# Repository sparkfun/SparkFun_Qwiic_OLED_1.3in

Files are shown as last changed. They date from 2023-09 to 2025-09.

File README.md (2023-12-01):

SparkFun Qwiic OLED 1.3in (128 x 64 white pixels)
========================================

Qwiic OLED 1.3in (128 x 64 white pixels) (https://www.sparkfun.com/products/23453)

[*Qwiic OLED 1.3in (128 x 64 white pixels) (LCD-23453)*](https://www.sparkfun.com/products/23453)

The SparkFun Qwiic OLED 1.3in (128 x 64 white pixels) Breakout is a Qwiic-enabled OLED display.

Repository Contents
-------------------

* **/Hardware** - Eagle design files (.brd, .sch)

Documentation
--------------
* **[Library](https://github.com/sparkfun/SparkFun_Qwiic_OLED_Arduino_Library)** - Latest Arduino library for the SparkFun Qwiic OLED 1.3in Breakout.
* **[Hookup Guide](https://docs.sparkfun.com/SparkFun_Qwiic_OLED_1.3in)** - Basic hookup guide for the SparkFun Qwiic OLED 1.3in

License Information
-------------------

This product is _**open source**_! 

Please review the LICENSE.md file for license information. 

If you have any questions or concerns on licensing, please contact techsupport@sparkfun.com.

Distributed as-is; no warranty is given.

- Your friends at SparkFun.

_<COLLABORATION CREDIT>_

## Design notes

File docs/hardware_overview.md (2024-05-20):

---
icon: material/cog
---

## OLED 

The OLED screen has a pixel resolution of 128 x 64, a panel size of 34.5 x 23.0 x 1.4 (mm), and an active area of 29.42 x 14.7 (mm). The driver chip is the SSD1306. More information can be found in the [datasheet](assets/board_files/SSD1306.pdf).

<figure markdown>
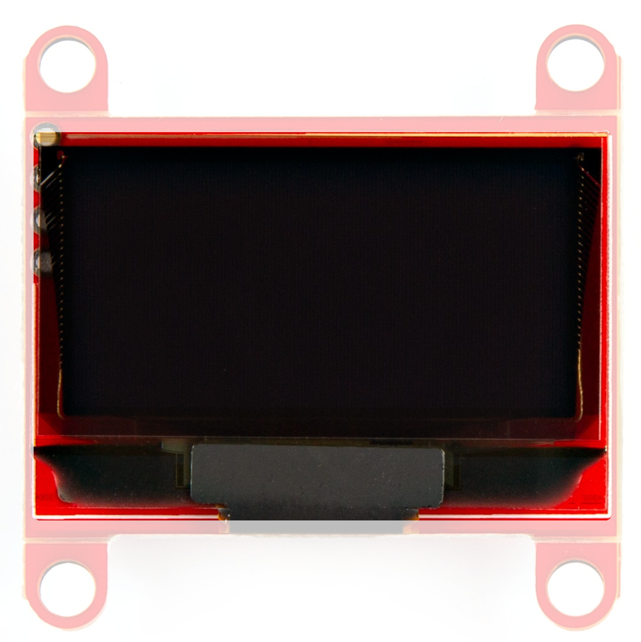
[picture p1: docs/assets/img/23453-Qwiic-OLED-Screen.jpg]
OLED Screen

<figcaption markdown>OLED Screen</figcaption>
</figure>

## Power

Ideally, power is supplied by the Qwiic connector, but the 3V3 and GND pins have been broken out to plated through holes on the side of the board (along with the Clock and Data Lines). Input voltage should not exceed <b>3.3V</b>, as there is no voltage regulation on this breakout. 

<figure markdown>
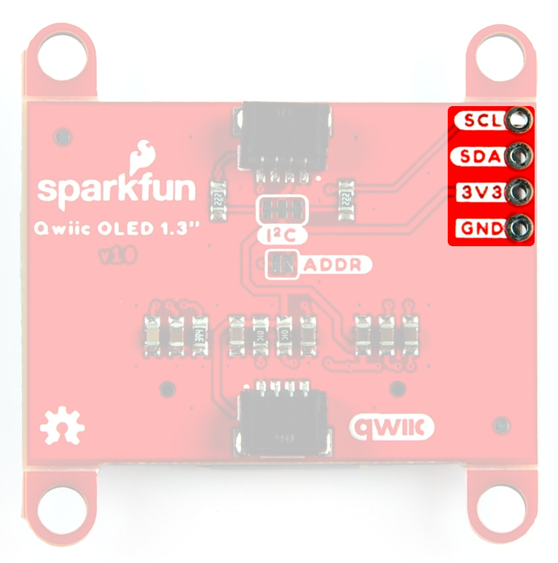
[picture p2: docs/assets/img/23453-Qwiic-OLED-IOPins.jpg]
Power Options

<figcaption markdown>Power Options</figcaption>
</figure>

## Qwiic connectors

The board includes Qwiic connectors that provide power and I<sup>2</sup>C connectivity simultaneously.

For users that need to solder directly to the board, the pins are also broken out on the edge PTH. The I<sup>2</sup>C data and clock lines are also tied to 2.2kΩ pull-up resistors.

<figure markdown>
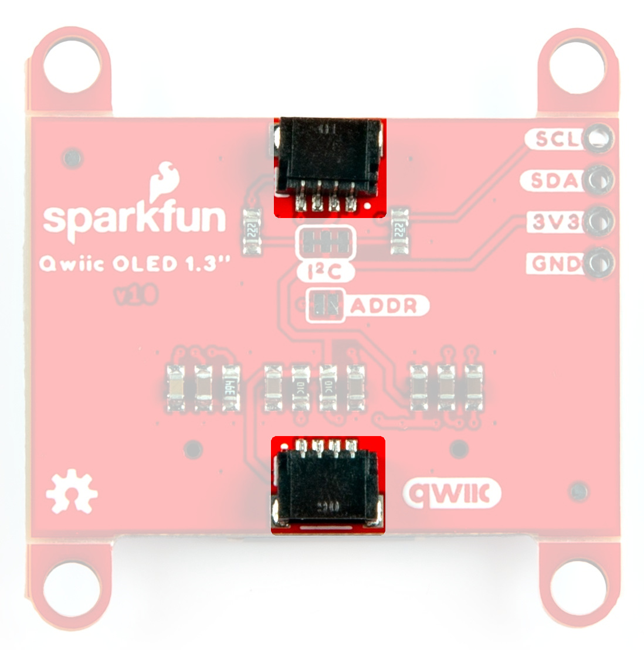
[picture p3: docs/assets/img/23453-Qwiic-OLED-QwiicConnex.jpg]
Qwiic connectors

<figcaption markdown>Qwiic connectors</figcaption>
</figure>

## Jumpers

??? note "Never modified a jumper before?"
	Check out our <a href="https://learn.sparkfun.com/tutorials/664">Jumper Pads and PCB Traces tutorial</a> for a quick introduction!
	<p align="center">
		<a href="https://learn.sparkfun.com/tutorials/664">
		Tutorial's thumbnail<br>
        How to Work with Jumper Pads and PCB Traces</a>
	</p>

### Address Jumper

The SparkFun Qwiic OLED 1.3in board has a default I<sup>2</sup>C address of 0x3D, but by soldering the address jumper on the back of the board, you can select 0x3C. 

<figure markdown>
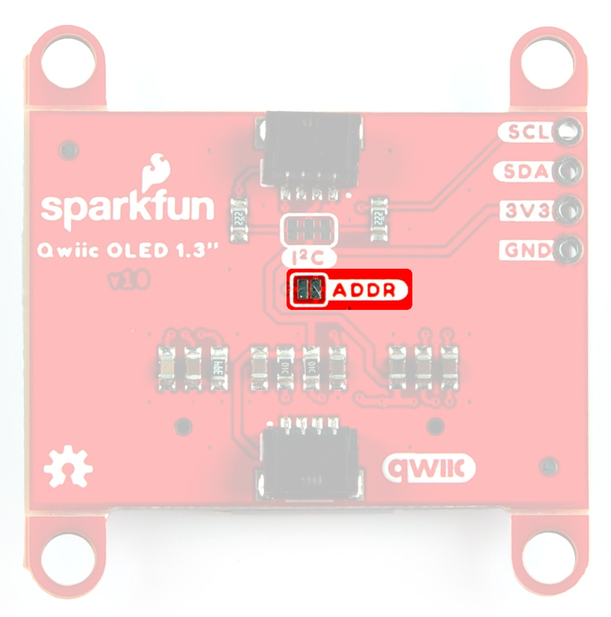
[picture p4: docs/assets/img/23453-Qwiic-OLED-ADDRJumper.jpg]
Address Jumper

<figcaption markdown>Address Jumper</figcaption>
</figure>

### I<sup>2</sup>C Jumper

Like our other Qwiic boards, the SparkFun Qwiic OLED 1.3in comes equipped with pull-up resistors on the clock and data pins. If you are daisy-chaining multiple Qwiic devices, you will want to cut this jumper; if multiple sensors are connected to the bus with the pull-up resistors enabled, the parallel equivalent resistance will create too strong of a pull-up for the bus to operate correctly. As a general rule of thumb, disable all but one pair of pull-up resistors if multiple devices are connected to the bus. To disable the pull up resistors, use an X-acto knife to cut the joint between the jumper pads highlighted below.

<figure markdown>
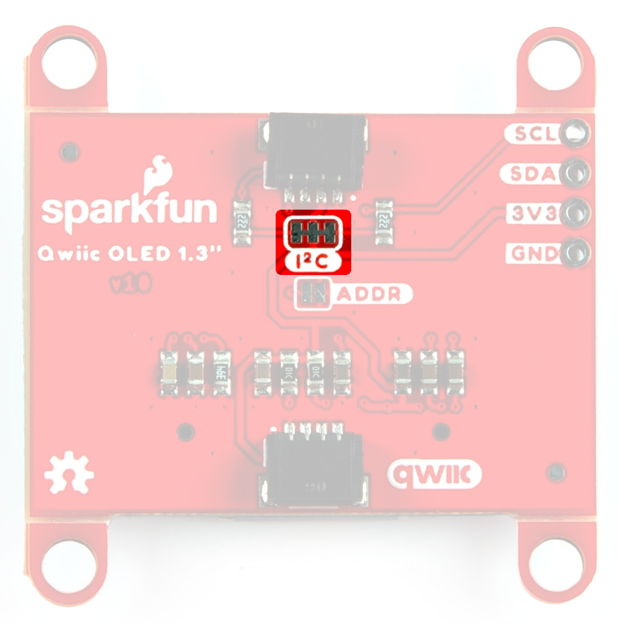
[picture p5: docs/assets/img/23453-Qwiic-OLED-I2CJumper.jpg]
I2C Jumper

<figcaption markdown>I<sup>2</sup>C Jumper</figcaption>
</figure>

## Board Dimensions

The board dimensions are illustrated in the drawing below; the listed measurements are in inches.

<figure markdown>
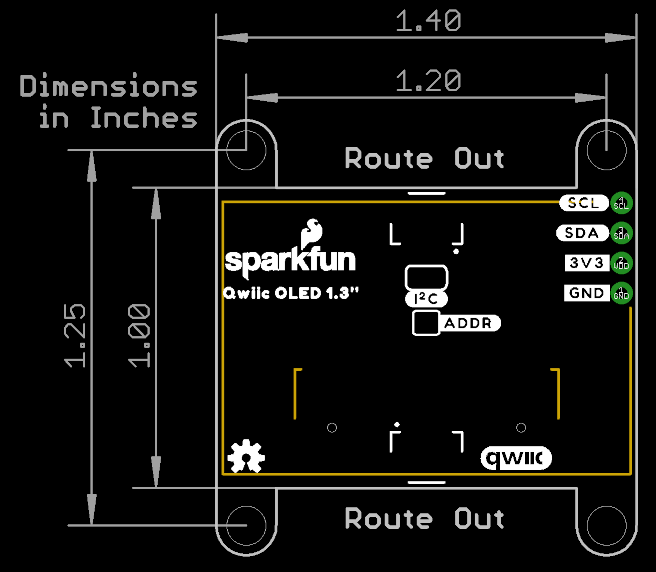
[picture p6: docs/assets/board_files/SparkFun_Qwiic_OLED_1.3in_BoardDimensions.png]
ESP32 Qwiic Pro Mini Board Dimensions

<figcaption markdown>SparkFun Qwiic OLED 1.3in Board Dimensions</figcaption>
</figure>

??? tip "Need more measurements?"
	For more information about the board's dimensions, users can download the [Eagle files](assets/board_files/Qwiic_OLED_1.3in.zip) for the 1" x 1" board, or the [Eagle files](assets/board_files/Qwiic_OLED_1.3in.zip) for the Mini board. These files can be opened in Eagle and additional measurements can be made with the dimensions tool.

	??? info ":octicons-download-16:{ .heart } Eagle - Free Download!"
		Eagle is a [CAD]("computer-aided design") program for electronics that is free to use for hobbyists and students. However, it does require an account registration to utilize the software.

		<center>
		[Download from<br>:autodesk-primary:{ .autodesk }](https://www.autodesk.com/products/eagle/free-download "Go to downloads page"){ .md-button .md-button--primary width="250px" }
		</center>
	
	??? info ":straight_ruler: Dimensions Tool"
		This video from Autodesk demonstrates how to utilize the dimensions tool in Eagle, to include additional measurements:

		<center>
		<div class="video">
		<iframe src="https://www.youtube.com/embed/dZLNd1FtNB8" title="EAGLE Dimension Tool" frameborder="0" allow="accelerometer; autoplay; clipboard-write; encrypted-media; gyroscope; picture-in-picture" allowfullscreen></iframe>
		</div>
		</center>

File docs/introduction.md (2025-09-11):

---
icon: material/book-open-page-variant
---

<div class="grid cards desc" markdown>

- <figure markdown>
    SparkFun Qwiic OLED 1.3in (128 x 64 white pixels) (LCD-23453) (https://www.sparkfun.com/sparkfun-qwiic-oled-1-3in-128x64.html)
		</figure>

    <center>
    [Purchase from SparkFun :fontawesome-solid-cart-plus:{ .heart }](https://www.sparkfun.com/sparkfun-qwiic-oled-1-3in-128x64.html){ .md-button .md-button--primary }
    </center>

</div>

## Required Materials

To follow along with this tutorial, you will need the following materials. You may not need everything though depending on what you have. Add it to your cart, read through the guide, and adjust the cart as necessary.

<div class="grid cards hide col-4" markdown>

-   <a href="https://www.sparkfun.com/products/23453">
      <figure markdown>
        SparkFun Qwiic OLED 1.3in (128 x 64 white pixels)
      </figure>
    </a>

    ---

    <a href="https://www.sparkfun.com/products/23453">
      <b>SparkFun Qwiic OLED 1.3in (128 x 64 white pixels)</b>
      <br />
      LCD-23453
    </a>

-   <a href="https://www.sparkfun.com/products/15123">
      <figure markdown>
        SparkFun RedBoard Qwiic
      </figure>
    </a>

    ---

    <a href="https://www.sparkfun.com/products/15123">
      <b>SparkFun RedBoard Qwiic</b>
      <br />
      DEV-15123
    </a>

-   <a href="https://www.sparkfun.com/products/14427">
      <figure markdown>
        Qwiic Cable - 100mm
      </figure>
    </a>

    ---

    <a href="https://www.sparkfun.com/products/14427">
      <b>Qwiic Cable - 100mm</b>
      <br>
      PRT-14427
    </a>
</div>

## Suggested Reading

This board is part of the [Qwiic connect system](https://www.sparkfun.com/qwiic). We recommend familiarizing yourself with the **Logic Levels** and **I<sup>2</sup>C** tutorials.  Click on the banner to learn more about [Qwiic products](https://www.sparkfun.com/qwiic).
<center>
<div align="center">
    <div style="top:5px;left:5px;background-color:Gray;position:relative">
        <div style="top:-5px;left:-5px;background-color:#ffffff;position:relative;border:1px solid black;">
            <a href="https://www.sparkfun.com/qwiic">Qwiic Connect System</a>
        </div>
    </div>
</div>
</center>

<center>
    <iframe width="600" height="327" src="https://www.youtube.com/embed/x0RDEHqFIF8" title="SparkFun's Qwiic Connect System" frameborder="0" allow="accelerometer; autoplay; clipboard-write; encrypted-media; gyroscope; picture-in-picture" allowfullscreen></iframe>
</center>

Below are a few tutorials that may help users familiarize themselves with various aspects of the board.

<div class="grid cards hide col-4" markdown>

-   <a href="https://learn.sparkfun.com/tutorials/how-to-solder-through-hole-soldering">
      <figure markdown>
        How to Solder: Through Hole Soldering
      </figure>
    </a>

    ---

    <a href="https://learn.sparkfun.com/tutorials/how-to-solder-through-hole-soldering">
      <b>How to Solder: Through Hole Soldering</b>
    </a>

-   <a href="https://learn.sparkfun.com/tutorials/analog-vs-digital">
      <figure markdown>
        Analog vs. Digital
      </figure>
    </a>

    ---

    <a href="https://learn.sparkfun.com/tutorials/analog-vs-digital">
      <b>Analog vs. Digital</b>
    </a>

-   <a href="https://learn.sparkfun.com/tutorials/serial-peripheral-interface-spi">
      <figure markdown>
        Serial Peripheral Interface
      </figure>
    </a>

    ---

    <a href="https://learn.sparkfun.com/tutorials/serial-peripheral-interface-spi">
      <b>Serial Peripheral Interface</b>
    </a>

-   <a href="https://learn.sparkfun.com/tutorials/i2c">
      <figure markdown>
        I2C
      </figure>
    </a>

    ---

    <a href="https://learn.sparkfun.com/tutorials/i2c">
      <b>I2C</b>
    </a>
</div>

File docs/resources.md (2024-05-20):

<!-- This section should include all the relevant documentation and product files (Eagle files, schematic, datasheet(s), landing pages, etc. and any relevant tutorials to go beyond the Hookup Guide.) -->

For more resources related to the SparkFun Qwiic OLED 1.3in, check out the links listed here: 

* [Schematic (PDF)](assets/board_files/SparkFun_Qwiic_OLED_1.3in_Schematic.pdf){ target="_blank" }
* [Eagle Files (ZIP)](assets/board_files/SparkFun_Qwiic_OLED_1.3in.zip){ target="_blank" }
* [Board Dimensions](assets/board_files/SparkFun_Qwiic_OLED_1.3in_BoardDimensions.png){ target="_blank" }
* [SH1306-OLED_Datasheet](assets/board_files/SSD1306.pdf){ target="_blank" }
* [Hardware GitHub Respository](https://github.com/sparkfun/SparkFun_Qwiic_OLED_1.3in){ target="_blank" }
* [Arduino Library GitHub Repo](https://github.com/sparkfun/SparkFun_Qwiic_OLED_Arduino_Library){ target="_blank" }

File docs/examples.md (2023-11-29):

---
icon: simple/arduino
---

The Arduino Library for the SparkFun OLED boards comes with a slew of examples to get you going.  Here we'll just run through a basic "the gang's all here" display. 

!!! note
    This example is pretty specific to the 1.3" OLED board. It requires the entirety of the pixels and would need to be heavily modified to be used by any of our other OLED boards. 

###Example: Display all the things

??? "Example Arduino Code"
	```    
        #include <Wire.h>

        #include <SparkFun_Qwiic_OLED.h> //http://librarymanager/All#SparkFun_Qwiic_OLED
        Qwiic1in3OLED myOLED; // 128x64

        // Fonts
        #include <res/qw_fnt_5x7.h>
        #include <res/qw_fnt_8x16.h>
        #include <res/qw_fnt_31x48.h>
        #include <res/qw_fnt_7segment.h>
        #include <res/qw_fnt_largenum.h>

        void setup()
        {
        Wire.begin();

        myOLED.begin();

        myOLED.erase();
        
        myOLED.setFont(QW_FONT_5X7);
        myOLED.text(0,0,"01234567");

        myOLED.setFont(QW_FONT_5X7);
        myOLED.text(0,8,"ABCDabcd");

        myOLED.setFont(QW_FONT_8X16);
        myOLED.text(48,0,"ABcd");

        myOLED.setFont(QW_FONT_8X16);
        myOLED.text(48,13,"efGH");

        myOLED.setFont(QW_FONT_7SEGMENT);
        myOLED.text(80,0,"0123");

        myOLED.setFont(QW_FONT_5X7);
        myOLED.text(80,17,"ijkLMNO");

        myOLED.setFont(QW_FONT_LARGENUM);
        myOLED.text(0,16,"012");

        myOLED.setFont(QW_FONT_31X48);
        myOLED.text(36,27,"ABC");

        myOLED.display();
        }

        void loop()
        {
        }

	```

Make sure you've selected the correct board and port in the Tools menu and then hit the upload button. You should see something similar to the following. 

<figure markdown>
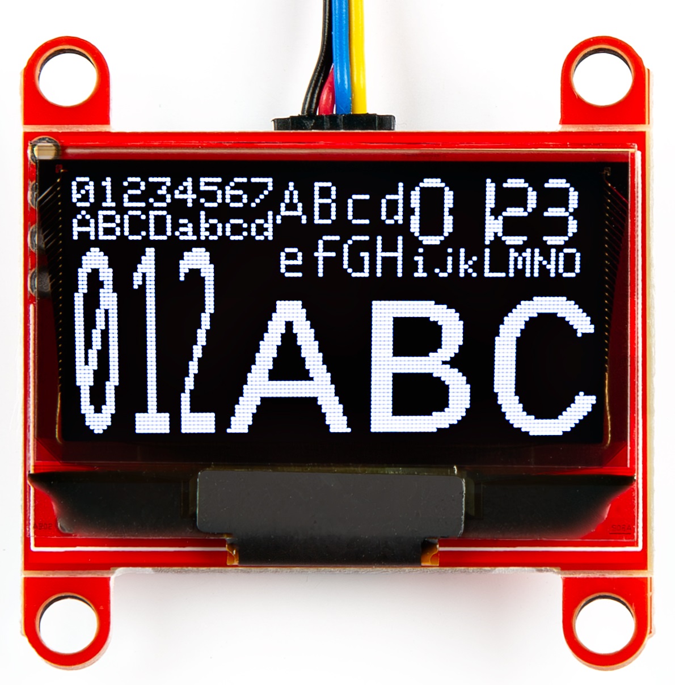
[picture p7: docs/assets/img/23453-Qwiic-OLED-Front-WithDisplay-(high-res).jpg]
Example DisplayScreen

<figcaption markdown>OLED Screen</figcaption>
</figure>

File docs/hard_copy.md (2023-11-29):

---
icon: material/book-open-variant
---

Need to download or print our hookup guide?

* [Print :fontawesome-solid-print:](../single_page) (Single-Page View)
    * To save as a `*.pdf` file, select the **Printer** or **Destination** labeled ++"Save as PDF"++. *(Instructions will vary based on the browser)*

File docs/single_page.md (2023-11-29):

---
hide:
  - navigation
  - toc
icon: fontawesome/solid/scroll
---

--8<-- "./docs/introduction.md:5"

# Hardware Overview
--8<-- "./docs/hardware_overview.md:5"

# Hardware Assembly
--8<-- "./docs/hardware_assembly.md:5"

# Software Setup and Programming
--8<-- "./docs/software_setup_and_programming.md:5"

# Arduino Example
--8<-- "./docs/examples.md:5"

# Resources:
--8<-- "./docs/resources.md"

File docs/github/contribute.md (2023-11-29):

# Contribute: Make an Augmentation!
Spot an improvement opportunity? Feel free to contribute to our open-source design and documentation. 

## :material-file-document-multiple:&nbsp;Improve our Documentation
All of this documentation can be modified by you! Please help us make it better.

* These pages are contained in the [`docs` folder](https://github.com/sparkfun/SparkFun_Qwiic_OLED_1.3in/tree/main/docs) of the [Qwiic OLED 1.3in](https://github.com/sparkfun/SparkFun_Qwiic_OLED_1.3in).

<!-- ### :material-source-pull:&nbsp;Submit a Correction -->
### Submit a Correction

1. With a GitHub account, [fork this repository](https://github.com/sparkfun/SparkFun_Qwiic_OLED_1.3in/fork).
2. Add your corrections or improvements to the markdown file.
3. File a pull request with your changes, and enjoy making the ~~words~~ ~~worlds~~ world a better place.
	* Once received, the documentation specialist will automatically be notified.
	* We will review your suggested improvements to make sure they are correct and fit within our documentation standards.

## :material-cog:&nbsp;Improve our Hardware Design
All of our designs are open-source! Please help us make it better.

* Our board design files are contained in the [`Hardware` folder](https://github.com/sparkfun/SparkFun_Qwiic_OLED_1.3in/tree/main/Hardware) of the [Qwiic OLED 1.3in](https://github.com/sparkfun/SparkFun_Qwiic_OLED_1.3in).

<!-- ### :material-source-pull:&nbsp;Submit a Design Enhancement -->
### Submit a Design Enhancement

1. With a GitHub account, [fork this repository](https://github.com/sparkfun/SparkFun_Qwiic_OLED_1.3in/fork).
2. Add your design augmentation(s)
3. File a pull request with your changes, and enjoy making the ~~words~~ ~~worlds~~ world a better place.
	1. Once received, the engineer in charge of the original design will automatically be notified.
	2. We will review your suggested improvement(s) to verify that they are within our board design standards and meet our product design requirements.
	3. If approved, we will flag these changes for our next board revision. Congrats! 🍻

		!!! info
			Even if your suggestion is accepted, these changes may not be immediately available for purchase. We may have to cycle through our current product inventory first.

## Contributors&nbsp;:clap:
Let's provide some recognition to the contributors for this project!

GitHub Contributors Image
<br>


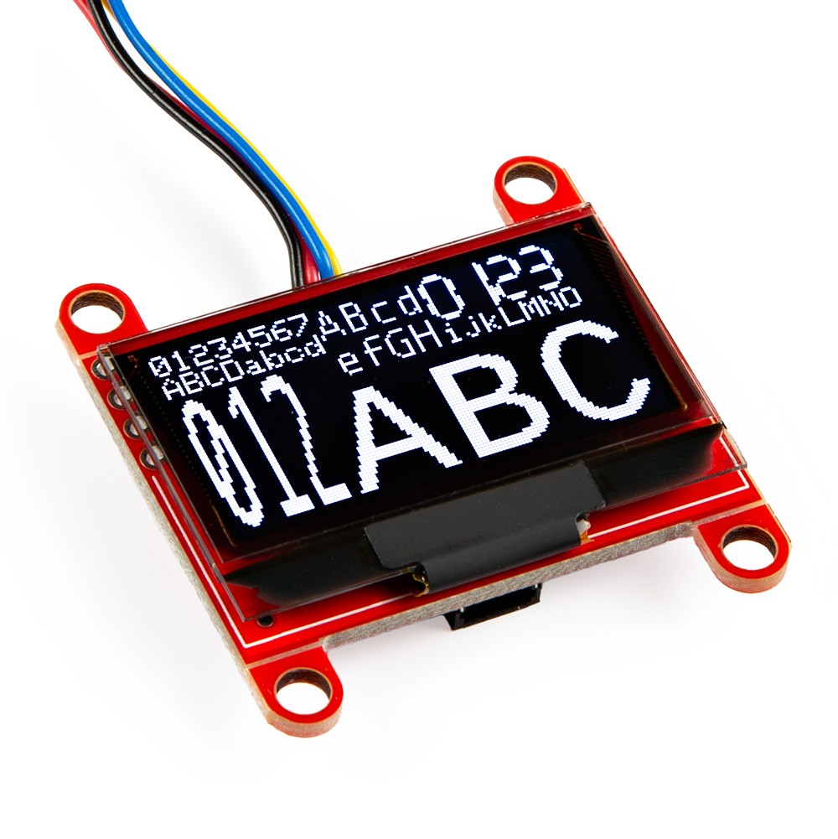
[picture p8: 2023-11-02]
docs/assets/img/23453-Qwiic-OLED-Feature-WithDisplay.jpg

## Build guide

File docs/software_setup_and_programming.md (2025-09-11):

---
icon: simple/arduino
---

!!! arduino

    ### Arduino IDE

    This example assumes you are using the latest version of the Arduino IDE on your desktop. If this is your first time using Arduino IDE and an library, please review the following tutorials.

    - [Installing the Arduino IDE](https://learn.sparkfun.com/tutorials/installing-arduino-ide)
    - [Installing an Arduino Library](https://learn.sparkfun.com/tutorials/installing-an-arduino-library)

SparkFun has leveraged our existing OLED library to work with the SparkFun Qwiic OLED 1.3 board. If you haven't already worked with our OLED boards, you can obtain this library through the Arduino Library Manager by searching for "Qwiic OLED" and installing the latest version. If you prefer downloading libraries manually, you can grab them from the GitHub Repository.

<div style="text-align: center"><a href="https://github.com/sparkfun/SparkFun_Qwiic_OLED_Arduino_Library/archive/refs/heads/main.zip" target="qwiic_oled_arduino_library" class="md-button">SparkFun Qwiic OLED Arduino Library GitHub</a></div>

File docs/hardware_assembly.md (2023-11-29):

---
icon: fontawesome/solid/screwdriver-wrench
---

SparkFun's Qwiic system makes components plug and play. Simply plug one end of your Qwiic cable into the Qwiic connector on your OLED screen and the other end of the Qwiic cable into the controller board (here we're using the RedBoard Qwiic). Now connect your controller board to the computer and voila. You're ready to rock. 

<figure markdown>
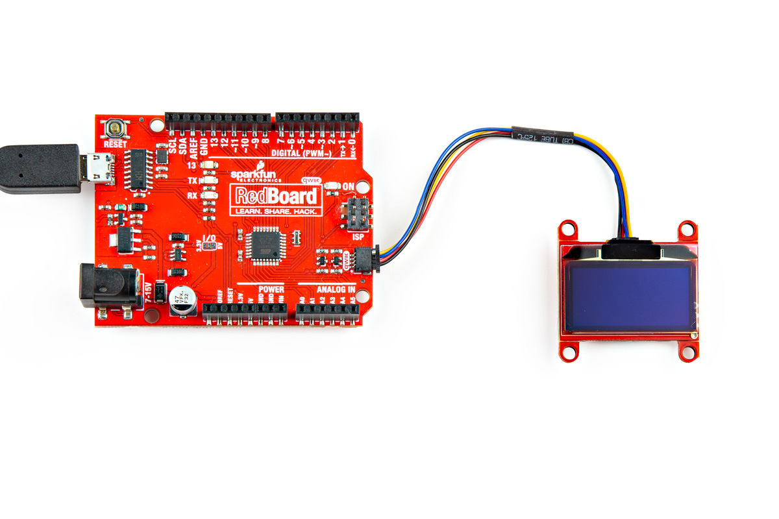
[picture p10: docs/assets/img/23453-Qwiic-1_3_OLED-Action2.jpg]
Qwiic OLED connected to the Qwiic RedBoard

<figcaption markdown>SparkFun Qwiic OLED connected to the SparkFun Qwiic RedBoard</figcaption>
</figure>

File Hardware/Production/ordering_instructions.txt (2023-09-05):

panel size, 122x136mm
PCB thickness, 1.6mm
number of layers, 2
soldermask color, Red
silkscreen color, White
oz copper, 1oz
finish, HASL lead free
stencils, top+bottom
pcs per panel, 9
min trace width, 0.2540mm / 0.0100in
min drill size, 0.3000mm / 0.0118in

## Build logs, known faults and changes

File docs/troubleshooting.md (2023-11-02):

!!! note
    <span class="glyphicon glyphicon-question-sign" aria-hidden="true"></span>
        <strong> Not working as expected and need help? </strong> <br /><br />

    If you need technical assistance and more information on a product that is not working as you expected, we recommend heading on over to the <a href="https://www.sparkfun.com/technical_assistance">SparkFun Technical Assistance</a> page for some initial troubleshooting. <br /><br />

    <div style="text-align: center"><a href="https://www.sparkfun.com/technical_assistance" target="sfe_technical_assistance" class="md-button">SparkFun Technical Assistance Page</a></div>

    If you don't find what you need there, the <a href="https://forum.sparkfun.com/index.php">SparkFun Forums</a> are a great place to find and ask for help. If this is your first visit, you'll need to <a href="https://forum.sparkfun.com/ucp.php?mode=register">create a Forum Account</a> to search product forums and post questions.<br /><br />

    <div style="text-align: center"><a href="https://forum.sparkfun.com/ucp.php?mode=register" class="md-button">Create New Forum Account</a>&nbsp;&nbsp;&nbsp;<a href="https://forum.sparkfun.com/index.php" class="md-button md-button--primary">Log Into SparkFun Forums</a></div>

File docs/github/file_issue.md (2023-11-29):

# Did we make a mistake?

Spot something wrong? Please let us know. 

<!-- Technical Assistance Box -->
!!! warning "Need Help?"
    If you need technical assistance or more information on a product that is not working as you expected, we recommend heading on over to the [SparkFun Technical Assistance](https://www.sparkfun.com/technical_assistanc) page for some initial troubleshooting. This **Submit Issues** page is not where users should seek assistance.

    <center>
    [SparkFun Technical Assistance Page](https://www.sparkfun.com/technical_assistance){ .md-button .md-button--primary }
    </center>
    
    If you can't find what you need there, the [SparkFun Forums](https://forum.sparkfun.com/index.php) is a great place to search the product forums and ask questions.
    
    !!! info "Account Registration Required"
        For your first visit to our forum, you'll need to create a [Forum Account](https://forum.sparkfun.com/ucp.php?mode=register) to post questions.

## Discrepancies in the Documentation

All of our documentation can be modified by you! Please help us make it better.

* The documentation files for these pages are contained in the [`docs` folder](https://github.com/sparkfun/SparkFun_Qwiic_OLED_1.3in/tree/main/docs) of the [Qwiic OLED 1.3in](https://github.com/sparkfun/SparkFun_Qwiic_OLED_1.3in).

### 🔍 Spot something wrong?

If a section of the documentation is incorrect, please [open an issue](https://github.com/sparkfun/SparkFun_Qwiic_OLED_1.3in/issues) and let us know.

### Do you have a suggested correction?

1. With a GitHub account, [fork this repository](https://github.com/sparkfun/SparkFun_Qwiic_OLED_1.3in/fork).
2. Add your correction(s) or improvement(s) to the markdown file(s)
3. File a pull request with your changes, and enjoy making the ~~words~~ ~~worlds~~ world a better place.
	* Once received, the documentation specialist will automatically be notified.
	* We will review your suggested improvement(s) to make sure they are correct and fit within our documentation standards.

## Problems in the Hardware Design

All of our designs are open-source! Please help us make it better.

* Our board design files are contained in the [`Hardware` folder](https://github.com/sparkfun/SparkFun_Qwiic_OLED_1.3in/tree/main/Hardware) of the [Qwiic OLED 1.3in](https://github.com/sparkfun/SparkFun_Qwiic_OLED_1.3in).

### Does something not make sense? 🤔

If part of the design is confusing, please [open an issue](https://github.com/sparkfun/SparkFun_Qwiic_OLED_1.3in/issues) and let us know.

### Did we forget to include an important function of the board? 🤦

If part of the board's functionality is missing, please [open an issue](https://github.com/sparkfun/SparkFun_Qwiic_OLED_1.3in/issues) and file a feature request.

!!! tip "Design Considerations"
	Please keep in mind that we may intentionally exclude certain functions of the board to meet our product design requirements.
	
	* *For example, our Qwiic Micro boards are intended to fit on a small board layout and only use I<sup>2</sup>C communication; therefore, we may not have the SPI and interrupt pins available for users.*

### Do you wish to contribute directly to improving the board design?

1. With a GitHub account, [fork this repository](https://github.com/sparkfun/SparkFun_Qwiic_OLED_1.3in/fork).
2. Add your design augmentation(s)
3. File a pull request with your changes, and enjoy making the ~~words~~ ~~worlds~~ world a better place.
	1. Once received, the engineer in charge of the original design will automatically be notified.
	2. We will review your suggested improvement(s) to verify that they are within our board design standards and meet our product design requirements.
	3. If approved, we will flag these changes for our next board revision. Congrats! 🍻

		!!! info
			Even if your suggestion is accepted, these changes may not be immediately available for purchase. We may have to cycle through our current product inventory first.

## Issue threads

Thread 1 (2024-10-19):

Does it work on a Raspberry Pico?

davidedelvento, 2024-10-19:
Would this display (or another one) work with a Pico? Obviously not with the Arduino library but with something else?

How about the original Teensy v4.1 from PJRC? Would that work out of the box?

Thanks

PaulZC, 2024-10-19:
Hi Davide (@davidedelvento ),

Earle Philhower's RP2040 Arduino board package supports I2C. If you use that, you should find that our [Qwiic OLED Library](https://github.com/sparkfun/SparkFun_Qwiic_OLED_Arduino_Library) works just fine.

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

Best wishes,
Paul

davidedelvento, 2024-10-19:
Sounds great! Thanks a lot Paul, especially for responding during the weekend.
Just for reference for others coming here (and not willing to Google :rofl: ), Earle's Arduino port is a at https://github.com/earlephilhower/arduino-pico

Closed 2024-10-19.

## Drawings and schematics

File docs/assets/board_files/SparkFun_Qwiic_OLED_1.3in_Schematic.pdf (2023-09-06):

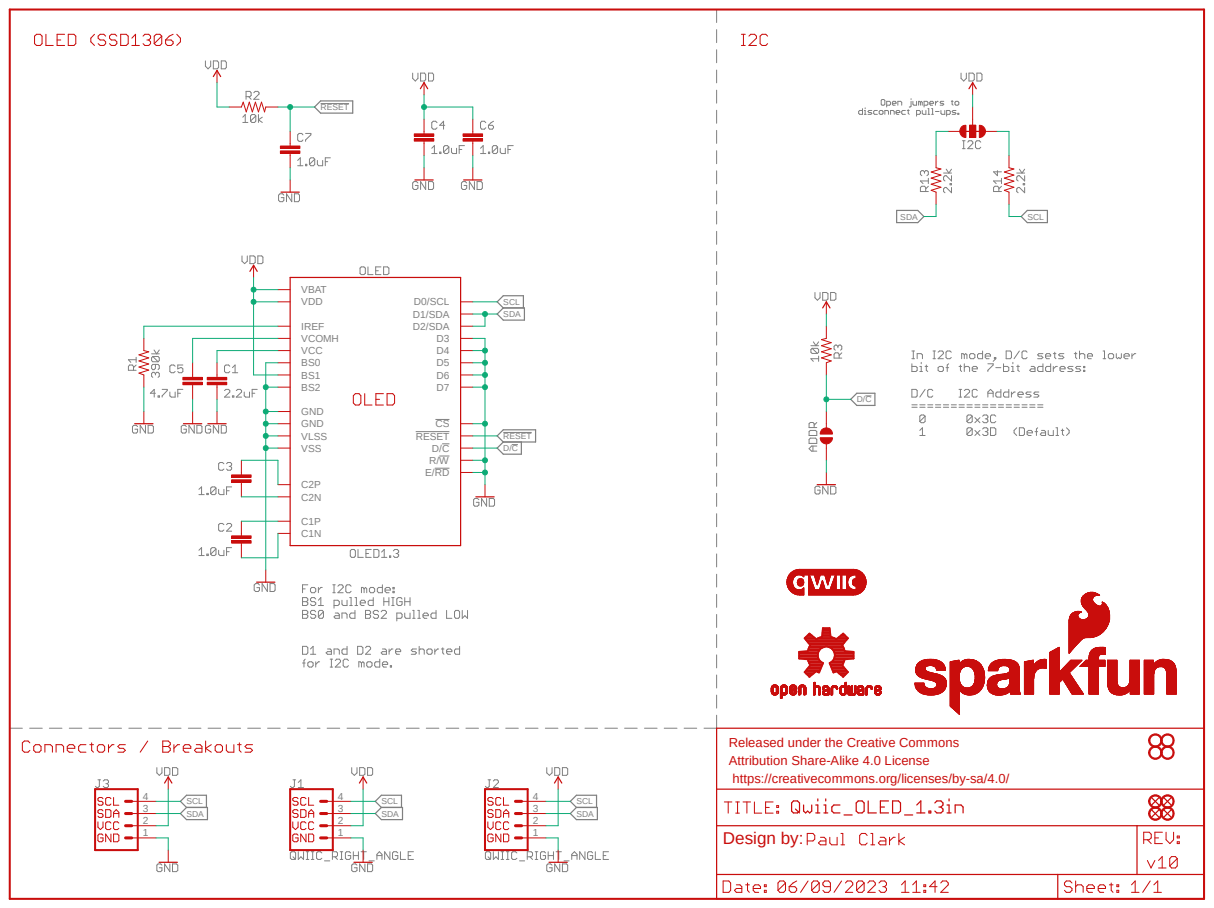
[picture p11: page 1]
CS RESET BS1 BS2 C1N; IREF; VCOMH; VDD; VLSS VSS; SDA; SCL; SCL RESET; RESET; Design by:

VBAT VCC
D0/SCL D1/SDA D2/SDAD3 D4 D5 D6 D7 E/RD GND GND

Released under the Creative Commons
Attribution Share-Alike 4.0 License
https://creativecommons.org/licenses/by-sa/4.0/

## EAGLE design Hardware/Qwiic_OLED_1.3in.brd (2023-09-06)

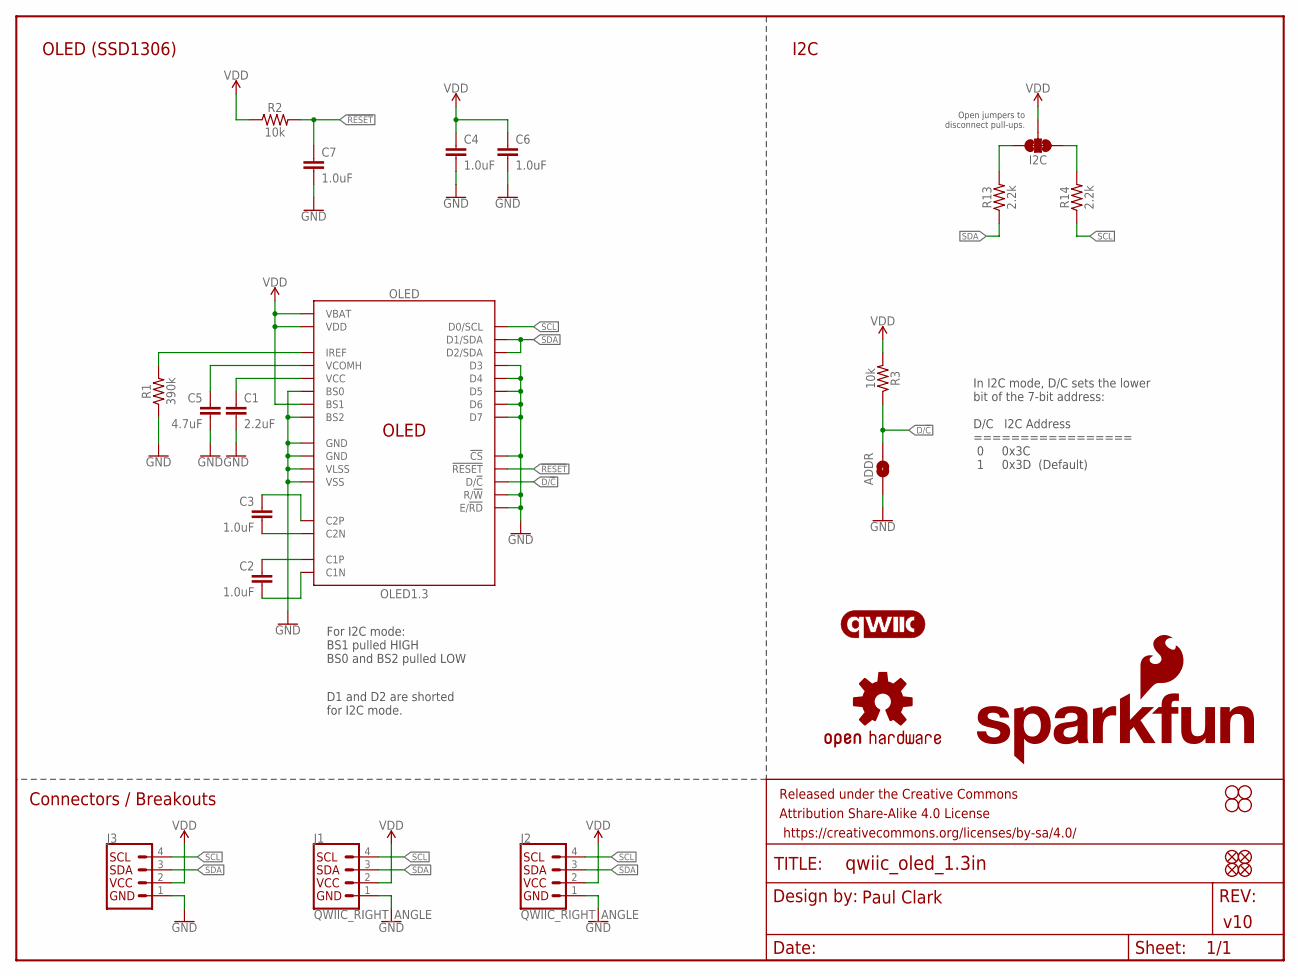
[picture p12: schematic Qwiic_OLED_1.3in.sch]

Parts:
ADDR: JUMPER-SMT_2_NO_SILK; SMT-JUMPER_2_NO_SILK
C1: 2.2uF; 0603
C2, C3, C4, C6, C7: 1.0uF; 0603
C5: 4.7uF; 0603
FID1, FID2, FID3, FID4: FIDUCIAL1X2; FIDUCIAL-1X2
FRAME1: FRAME-LETTER; CREATIVE_COMMONS
H1, H2, H3, H4: STAND-OFF
I2C: JUMPER-SMT_3_2-NC_TRACE_SILK; SMT-JUMPER_3_2-NC_TRACE_SILK
J1, J2: QWIIC_RIGHT_ANGLE; JST04_1MM_RA
J3: I2C_STANDARD_NO_SILK; 1X04_NO_SILK
LOGO1: QWIIC_LOGO_6MM; QWIIC_6MM
LOGO3: OSHW-LOGOS; OSHW-LOGO-S
LOGO4: SFE_LOGO_NAME_FLAME.1_INCH; SFE_LOGO_NAME_FLAME_.1
OLED: OLED1.3; OLED-1.3-128X64
R1: 390k; 0603
R2, R3: 10k; 0603
R13, R14: 2.2k; 0603

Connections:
!RESET!: C7.1, OLED.14 (!RESET!), R2.2
C1N: C2.2, OLED.5 (C1N)
C1P: C2.1, OLED.4 (C1P)
C2N: C3.2, OLED.3 (C2N)
C2P: C3.1, OLED.2 (C2P)
D/!C!: ADDR.2, OLED.15 (D/!C!), R3.1
GND: ADDR.1, C1.2, C4.2, C5.2, C6.2, C7.2, J1.1, J2.1, J3.1 (GND), OLED.1 (GND), OLED.8 (VSS), OLED.10 (BS0), OLED.12 (BS2), OLED.13 (!CS!), OLED.16 (R/!W!), OLED.17 (E/!RD!), OLED.21 (D3), OLED.22 (D4), OLED.23 (D5), OLED.24 (D6), OLED.25 (D7), OLED.29 (VLSS), OLED.30 (GND), R1.1
IREF: OLED.26 (IREF), R1.2
unnamed: I2C.3, R13.2
unnamed: I2C.1, R14.2
SCL: J1.4, J2.4, J3.4 (SCL), OLED.18 (D0/SCL), R14.1
SDA: J1.3, J2.3, J3.3 (SDA), OLED.19 (D1/SDA), OLED.20 (D2/SDA), R13.1
VCC: C1.1, OLED.28 (VCC)
VCOMH: C5.1, OLED.27 (VCOMH)
VDD: C4.1, C6.1, I2C.2, J1.2, J2.2, J3.2 (VCC), OLED.6 (VBAT), OLED.9 (VDD), OLED.11 (BS1), R2.1, R3.2

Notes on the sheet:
v10
D1 and D2 are shorted for I2C mode.
In I2C mode, D/C sets the lower bit of the 7-bit address: D/C I2C Address ================= 0 0x3C 1 0x3D (Default)
For I2C mode: BS1 pulled HIGH BS0 and BS2 pulled LOW
Open jumpers to disconnect pull-ups.
Paul Clark
OLED (SSD1306)
Connectors / Breakouts
I2C

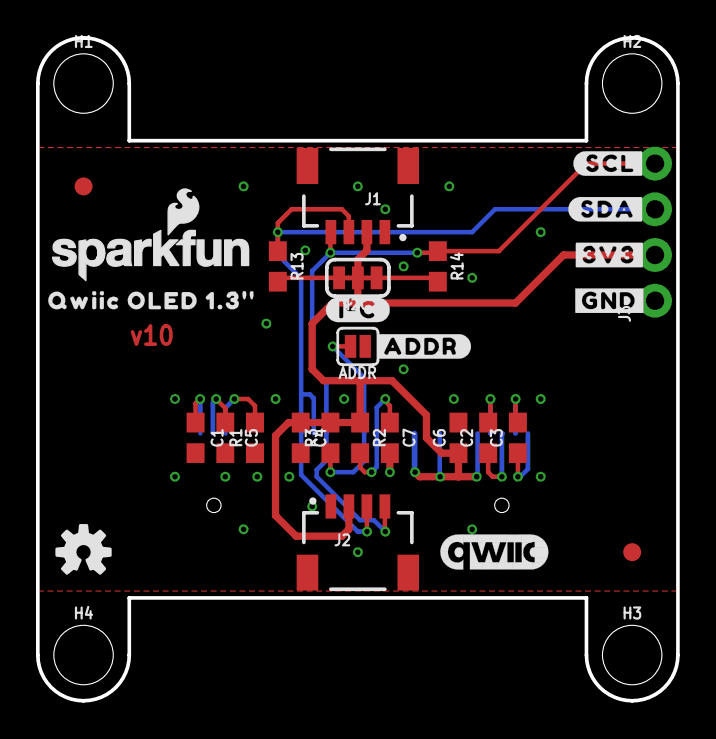
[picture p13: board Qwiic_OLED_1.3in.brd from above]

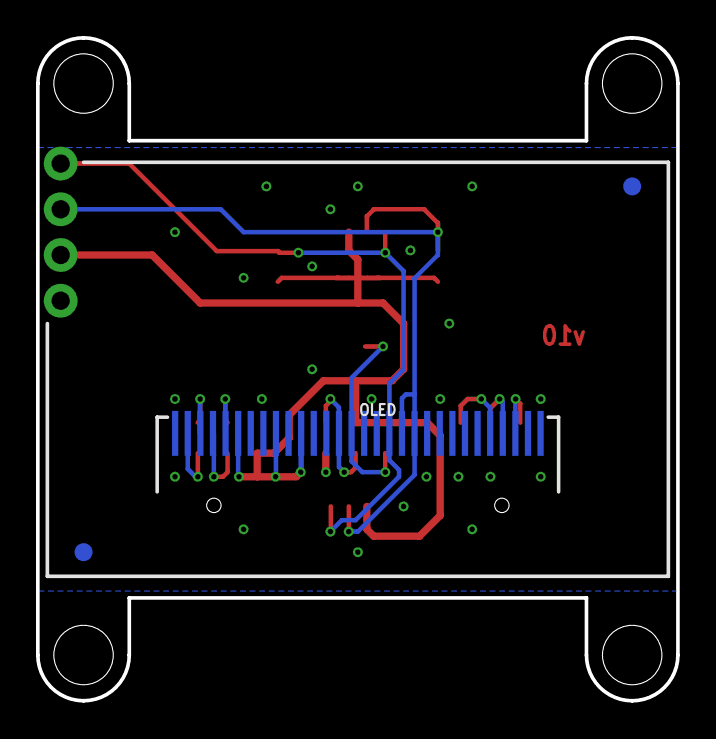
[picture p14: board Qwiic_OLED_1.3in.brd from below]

Board: 2 copper layers, 35.6 x 36.8 mm, 37 parts (3 on the bottom side), 15 nets.

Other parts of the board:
U$1: QWIIC_OLED_1#3##0
U$2: #I�C#2
U$3: #3V3#2
U$4: #ADDR#5
U$5: #GND#4
U$6: #SCL#0
U$7: #SDA#1

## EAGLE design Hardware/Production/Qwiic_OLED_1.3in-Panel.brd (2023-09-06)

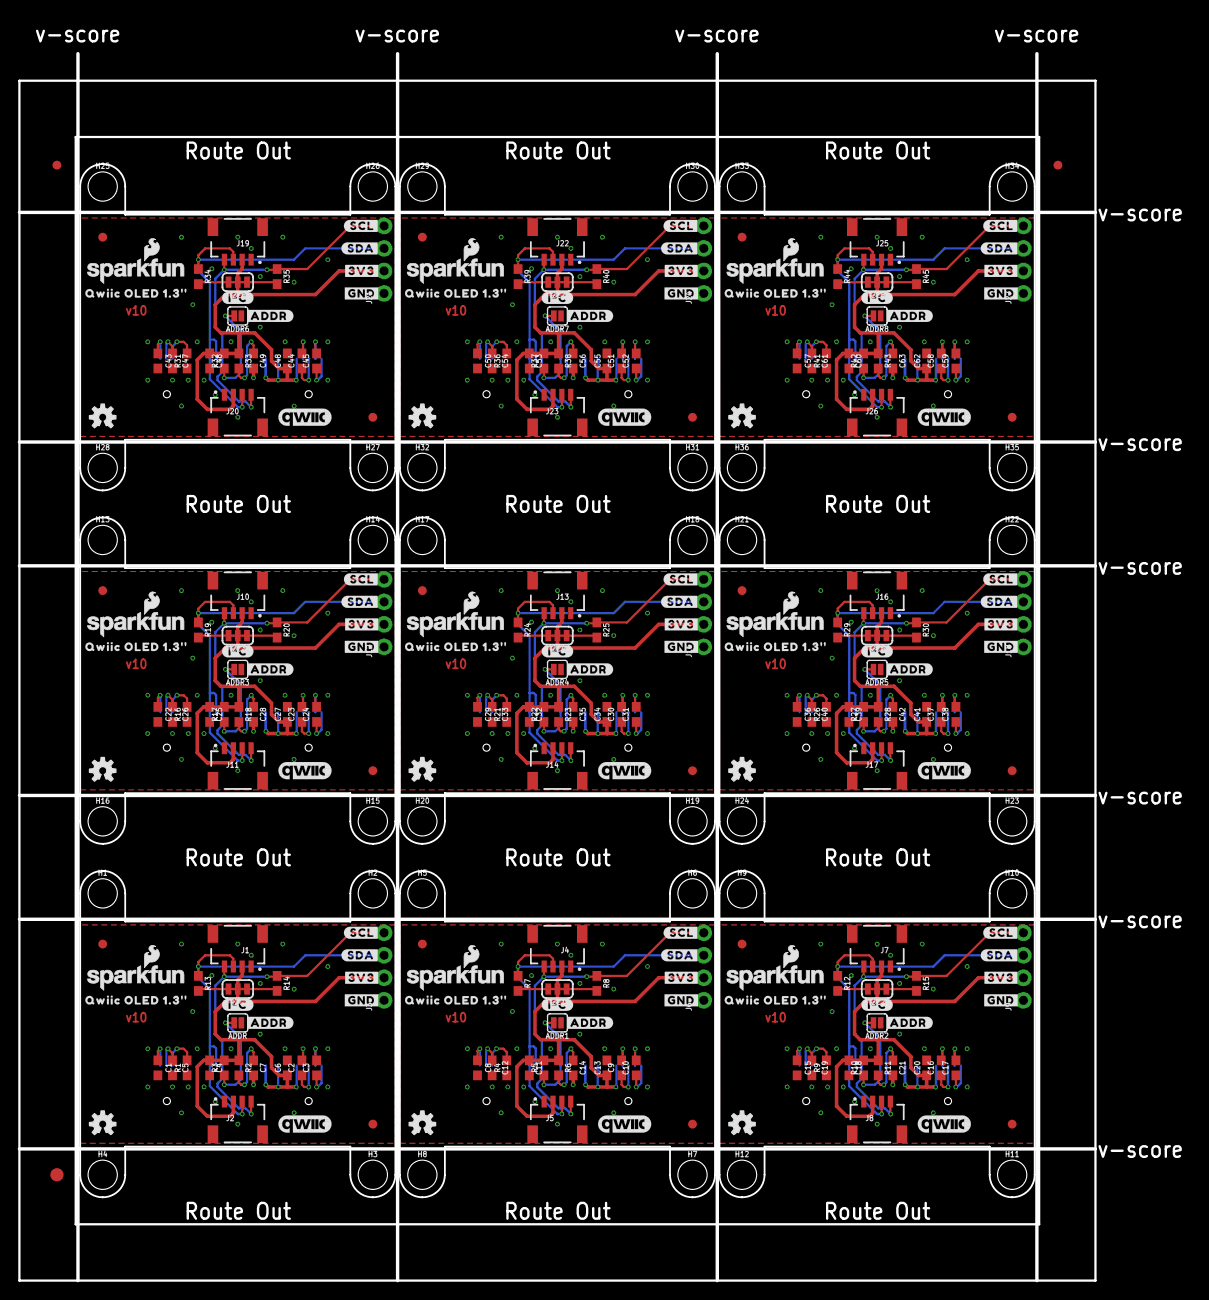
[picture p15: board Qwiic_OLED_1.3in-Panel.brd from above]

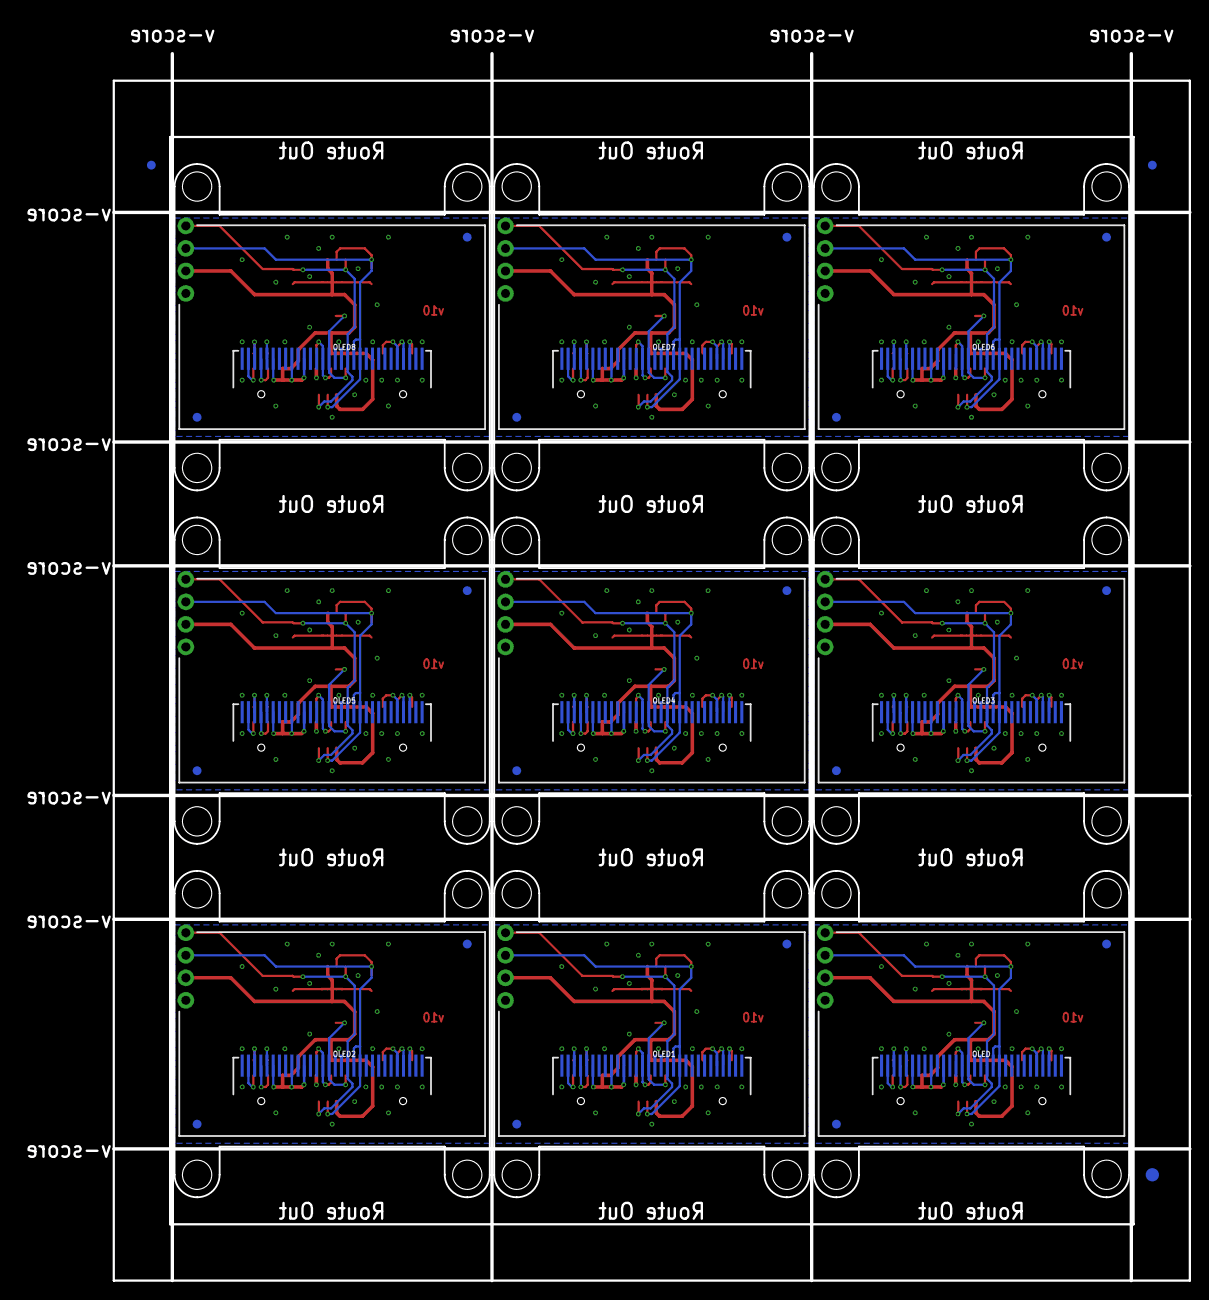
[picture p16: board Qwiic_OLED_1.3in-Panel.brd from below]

Board: 2 copper layers, 121.4 x 138.4 mm, 330 parts (30 on the bottom side), 135 nets.

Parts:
ADDR, ADDR1, ADDR2, ADDR3, ADDR4, ADDR5, ADDR6, ADDR7, ADDR8: JUMPER-SMT_2_NO_SILK; SMT-JUMPER_2_NO_SILK
C1, C8, C15, C22, C29, C36, C43, C50, C57: 2.2uF; 0603
C2, C3, C4, C6, C7, C9, C10, C11, C13, C14, C16, C17, C18, C20, C21, C23, C24, C25, C27, C28, C30, C31, C32, C34, C35, C37, C38, C39, C41, C42, C44, C45, C46, C48, C49, C51, C52, C53, C55, C56, C58, C59, C60, C62, C63: 1.0uF; 0603
C5, C12, C19, C26, C33, C40, C47, C54, C61: 4.7uF; 0603
E$1, E$2, E$3, E$4: FIDUCIAL-1X2
E$5, E$6: FIDUCIAL-1.5X3
FID1, FID2, FID3, FID4, FID5, FID6, FID7, FID8, FID9, FID10, FID11, FID12, FID13, FID14, FID15, FID16, FID17, FID18, FID19, FID20, FID21, FID22, FID23, FID24, FID25, FID26, FID27, FID28, FID29, FID30, FID31, FID32, FID33, FID34, FID35, FID36: FIDUCIAL1X2; FIDUCIAL-1X2
H1, H2, H3, H4, H5, H6, H7, H8, H9, H10, H11, H12, H13, H14, H15, H16, H17, H18, H19, H20, H21, H22, H23, H24, H25, H26, H27, H28, H29, H30, H31, H32, H33, H34, H35, H36: STAND-OFF
I2C, I2C1, I2C2, I2C3, I2C4, I2C5, I2C6, I2C7, I2C8: JUMPER-SMT_3_2-NC_TRACE_SILK; SMT-JUMPER_3_2-NC_TRACE_SILK
J1, J2, J4, J5, J7, J8, J10, J11, J13, J14, J16, J17, J19, J20, J22, J23, J25, J26: QWIIC_RIGHT_ANGLE; JST04_1MM_RA
J3, J6, J9, J12, J15, J18, J21, J24, J27: 1X04_NO_SILK
LOGO1, LOGO6, LOGO9, LOGO12, LOGO15, LOGO18, LOGO21, LOGO24, LOGO27: QWIIC_LOGO_6MM; QWIIC_6MM
LOGO2, LOGO3, LOGO7, LOGO10, LOGO13, LOGO16, LOGO19, LOGO22, LOGO25: OSHW-LOGOS; OSHW-LOGO-S
LOGO4, LOGO5, LOGO8, LOGO11, LOGO14, LOGO17, LOGO20, LOGO23, LOGO26: SFE_LOGO_NAME_FLAME.1_INCH; SFE_LOGO_NAME_FLAME_.1
OLED, OLED1, OLED2, OLED3, OLED4, OLED5, OLED6, OLED7, OLED8: OLED1.3; OLED-1.3-128X64
R1, R4, R9, R16, R21, R26, R31, R36, R41: 390k; 0603
R2, R3, R5, R6, R10, R11, R17, R18, R22, R23, R27, R28, R32, R33, R37, R38, R42, R43: 10k; 0603
R7, R8, R12, R13, R14, R15, R19, R20, R24, R25, R29, R30, R34, R35, R39, R40, R44, R45: 2.2k; 0603
U$1, U$8, U$15, U$22, U$29, U$36, U$43, U$50, U$57: QWIIC_OLED_1#3##0
U$2, U$9, U$16, U$23, U$30, U$37, U$44, U$51, U$58: #I�C#2
U$3, U$10, U$17, U$24, U$31, U$38, U$45, U$52, U$59: #3V3#2
U$4, U$11, U$18, U$25, U$32, U$39, U$46, U$53, U$60: #ADDR#5
U$5, U$12, U$19, U$26, U$33, U$40, U$47, U$54, U$61: #GND#4
U$6, U$13, U$20, U$27, U$34, U$41, U$48, U$55, U$62: #SCL#0
U$7, U$14, U$21, U$28, U$35, U$42, U$49, U$56, U$63: #SDA#1

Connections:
!RESET!: C7.1, OLED.14, R2.2
!RESET!1: C14.1, OLED1.14, R6.2
!RESET!2: C21.1, OLED2.14, R11.2
!RESET!3: C28.1, OLED3.14, R18.2
!RESET!4: C35.1, OLED4.14, R23.2
!RESET!5: C42.1, OLED5.14, R28.2
!RESET!6: C49.1, OLED6.14, R33.2
!RESET!7: C56.1, OLED7.14, R38.2
!RESET!8: C63.1, OLED8.14, R43.2
C1N: C2.2, OLED.5
C1N1: C9.2, OLED1.5
C1N2: C16.2, OLED2.5
C1N3: C23.2, OLED3.5
C1N4: C30.2, OLED4.5
C1N5: C37.2, OLED5.5
C1N6: C44.2, OLED6.5
C1N7: C51.2, OLED7.5
C1N8: C58.2, OLED8.5
C1P: C2.1, OLED.4
C1P1: C9.1, OLED1.4
C1P2: C16.1, OLED2.4
C1P3: C23.1, OLED3.4
C1P4: C30.1, OLED4.4
C1P5: C37.1, OLED5.4
C1P6: C44.1, OLED6.4
C1P7: C51.1, OLED7.4
C1P8: C58.1, OLED8.4
C2N: C3.2, OLED.3
C2N1: C10.2, OLED1.3
C2N2: C17.2, OLED2.3
C2N3: C24.2, OLED3.3
C2N4: C31.2, OLED4.3
C2N5: C38.2, OLED5.3
C2N6: C45.2, OLED6.3
C2N7: C52.2, OLED7.3
C2N8: C59.2, OLED8.3
C2P: C3.1, OLED.2
C2P1: C10.1, OLED1.2
C2P2: C17.1, OLED2.2
C2P3: C24.1, OLED3.2
C2P4: C31.1, OLED4.2
C2P5: C38.1, OLED5.2
C2P6: C45.1, OLED6.2
C2P7: C52.1, OLED7.2
C2P8: C59.1, OLED8.2
D/!C!: ADDR.2, OLED.15, R3.1
D/!C!1: ADDR1.2, OLED1.15, R5.1
D/!C!2: ADDR2.2, OLED2.15, R10.1
D/!C!3: ADDR3.2, OLED3.15, R17.1
D/!C!4: ADDR4.2, OLED4.15, R22.1
D/!C!5: ADDR5.2, OLED5.15, R27.1
D/!C!6: ADDR6.2, OLED6.15, R32.1
D/!C!7: ADDR7.2, OLED7.15, R37.1
D/!C!8: ADDR8.2, OLED8.15, R42.1
GND: ADDR.1, C1.2, C4.2, C5.2, C6.2, C7.2, J1.1, J2.1, J3.1, OLED.1, OLED.8, OLED.10, OLED.12, OLED.13, OLED.16, OLED.17, OLED.21, OLED.22, OLED.23, OLED.24, OLED.25, OLED.29, OLED.30, R1.1
GND1: ADDR1.1, C8.2, C11.2, C12.2, C13.2, C14.2, J4.1, J5.1, J6.1, OLED1.1, OLED1.8, OLED1.10, OLED1.12, OLED1.13, OLED1.16, OLED1.17, OLED1.21, OLED1.22, OLED1.23, OLED1.24, OLED1.25, OLED1.29, OLED1.30, R4.1
GND2: ADDR2.1, C15.2, C18.2, C19.2, C20.2, C21.2, J7.1, J8.1, J9.1, OLED2.1, OLED2.8, OLED2.10, OLED2.12, OLED2.13, OLED2.16, OLED2.17, OLED2.21, OLED2.22, OLED2.23, OLED2.24, OLED2.25, OLED2.29, OLED2.30, R9.1
GND3: ADDR3.1, C22.2, C25.2, C26.2, C27.2, C28.2, J10.1, J11.1, J12.1, OLED3.1, OLED3.8, OLED3.10, OLED3.12, OLED3.13, OLED3.16, OLED3.17, OLED3.21, OLED3.22, OLED3.23, OLED3.24, OLED3.25, OLED3.29, OLED3.30, R16.1
GND4: ADDR4.1, C29.2, C32.2, C33.2, C34.2, C35.2, J13.1, J14.1, J15.1, OLED4.1, OLED4.8, OLED4.10, OLED4.12, OLED4.13, OLED4.16, OLED4.17, OLED4.21, OLED4.22, OLED4.23, OLED4.24, OLED4.25, OLED4.29, OLED4.30, R21.1
GND5: ADDR5.1, C36.2, C39.2, C40.2, C41.2, C42.2, J16.1, J17.1, J18.1, OLED5.1, OLED5.8, OLED5.10, OLED5.12, OLED5.13, OLED5.16, OLED5.17, OLED5.21, OLED5.22, OLED5.23, OLED5.24, OLED5.25, OLED5.29, OLED5.30, R26.1
GND6: ADDR6.1, C43.2, C46.2, C47.2, C48.2, C49.2, J19.1, J20.1, J21.1, OLED6.1, OLED6.8, OLED6.10, OLED6.12, OLED6.13, OLED6.16, OLED6.17, OLED6.21, OLED6.22, OLED6.23, OLED6.24, OLED6.25, OLED6.29, OLED6.30, R31.1
GND7: ADDR7.1, C50.2, C53.2, C54.2, C55.2, C56.2, J22.1, J23.1, J24.1, OLED7.1, OLED7.8, OLED7.10, OLED7.12, OLED7.13, OLED7.16, OLED7.17, OLED7.21, OLED7.22, OLED7.23, OLED7.24, OLED7.25, OLED7.29, OLED7.30, R36.1
GND8: ADDR8.1, C57.2, C60.2, C61.2, C62.2, C63.2, J25.1, J26.1, J27.1, OLED8.1, OLED8.8, OLED8.10, OLED8.12, OLED8.13, OLED8.16, OLED8.17, OLED8.21, OLED8.22, OLED8.23, OLED8.24, OLED8.25, OLED8.29, OLED8.30, R41.1
IREF: OLED.26, R1.2
IREF1: OLED1.26, R4.2
IREF2: OLED2.26, R9.2
IREF3: OLED3.26, R16.2
IREF4: OLED4.26, R21.2
IREF5: OLED5.26, R26.2
IREF6: OLED6.26, R31.2
IREF7: OLED7.26, R36.2
IREF8: OLED8.26, R41.2
unnamed: I2C1.3, R7.2
unnamed: I2C1.1, R8.2
unnamed: I2C2.3, R12.2
unnamed: I2C.3, R13.2
unnamed: I2C.1, R14.2
unnamed: I2C2.1, R15.2
unnamed: I2C3.3, R19.2
unnamed: I2C3.1, R20.2
unnamed: I2C4.3, R24.2
unnamed: I2C4.1, R25.2
unnamed: I2C5.3, R29.2
unnamed: I2C5.1, R30.2
unnamed: I2C6.3, R34.2
unnamed: I2C6.1, R35.2
unnamed: I2C7.3, R39.2
unnamed: I2C7.1, R40.2
unnamed: I2C8.3, R44.2
unnamed: I2C8.1, R45.2
SCL: J1.4, J2.4, J3.4, OLED.18, R14.1
SCL1: J4.4, J5.4, J6.4, OLED1.18, R8.1
SCL2: J7.4, J8.4, J9.4, OLED2.18, R15.1
SCL3: J10.4, J11.4, J12.4, OLED3.18, R20.1
SCL4: J13.4, J14.4, J15.4, OLED4.18, R25.1
SCL5: J16.4, J17.4, J18.4, OLED5.18, R30.1
SCL6: J19.4, J20.4, J21.4, OLED6.18, R35.1
SCL7: J22.4, J23.4, J24.4, OLED7.18, R40.1
SCL8: J25.4, J26.4, J27.4, OLED8.18, R45.1
SDA: J1.3, J2.3, J3.3, OLED.19, OLED.20, R13.1
SDA1: J4.3, J5.3, J6.3, OLED1.19, OLED1.20, R7.1
SDA2: J7.3, J8.3, J9.3, OLED2.19, OLED2.20, R12.1
SDA3: J10.3, J11.3, J12.3, OLED3.19, OLED3.20, R19.1
SDA4: J13.3, J14.3, J15.3, OLED4.19, OLED4.20, R24.1
SDA5: J16.3, J17.3, J18.3, OLED5.19, OLED5.20, R29.1
SDA6: J19.3, J20.3, J21.3, OLED6.19, OLED6.20, R34.1
SDA7: J22.3, J23.3, J24.3, OLED7.19, OLED7.20, R39.1
SDA8: J25.3, J26.3, J27.3, OLED8.19, OLED8.20, R44.1
VCC: C1.1, OLED.28
VCC1: C8.1, OLED1.28
VCC2: C15.1, OLED2.28
VCC3: C22.1, OLED3.28
VCC4: C29.1, OLED4.28
VCC5: C36.1, OLED5.28
VCC6: C43.1, OLED6.28
VCC7: C50.1, OLED7.28
VCC8: C57.1, OLED8.28
VCOMH: C5.1, OLED.27
VCOMH1: C12.1, OLED1.27
VCOMH2: C19.1, OLED2.27
VCOMH3: C26.1, OLED3.27
VCOMH4: C33.1, OLED4.27
VCOMH5: C40.1, OLED5.27
VCOMH6: C47.1, OLED6.27
VCOMH7: C54.1, OLED7.27
VCOMH8: C61.1, OLED8.27
VDD: C4.1, C6.1, I2C.2, J1.2, J2.2, J3.2, OLED.6, OLED.9, OLED.11, R2.1, R3.2
VDD1: C11.1, C13.1, I2C1.2, J4.2, J5.2, J6.2, OLED1.6, OLED1.9, OLED1.11, R5.2, R6.1
VDD2: C18.1, C20.1, I2C2.2, J7.2, J8.2, J9.2, OLED2.6, OLED2.9, OLED2.11, R10.2, R11.1
VDD3: C25.1, C27.1, I2C3.2, J10.2, J11.2, J12.2, OLED3.6, OLED3.9, OLED3.11, R17.2, R18.1
VDD4: C32.1, C34.1, I2C4.2, J13.2, J14.2, J15.2, OLED4.6, OLED4.9, OLED4.11, R22.2, R23.1
VDD5: C39.1, C41.1, I2C5.2, J16.2, J17.2, J18.2, OLED5.6, OLED5.9, OLED5.11, R27.2, R28.1
VDD6: C46.1, C48.1, I2C6.2, J19.2, J20.2, J21.2, OLED6.6, OLED6.9, OLED6.11, R32.2, R33.1
VDD7: C53.1, C55.1, I2C7.2, J22.2, J23.2, J24.2, OLED7.6, OLED7.9, OLED7.11, R37.2, R38.1
VDD8: C60.1, C62.1, I2C8.2, J25.2, J26.2, J27.2, OLED8.6, OLED8.9, OLED8.11, R42.2, R43.1

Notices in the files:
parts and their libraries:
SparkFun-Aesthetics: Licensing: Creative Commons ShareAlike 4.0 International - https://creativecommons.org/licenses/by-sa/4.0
